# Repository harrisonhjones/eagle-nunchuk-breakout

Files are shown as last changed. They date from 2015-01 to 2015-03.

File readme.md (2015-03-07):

# Nunchuk Breakout
A breakout board for the Wii Nunchuk

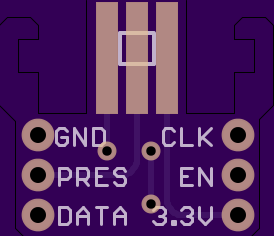
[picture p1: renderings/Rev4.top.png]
PNG


## Version History

| Revision # | Schematic | Board | BOM | Top | Bottom |  Purchase Link | Notes |
| ---- | ---- | ---- | ---- | ---- | ---- | ---- | ---- |
| 0 | N/A | N/A | N/A | N/A | N/A | N/A | Initial Version. No locking mechanism. Produced on a PCB mill @ college. Works |
| 1 | N/A | N/A | N/A | N/A | N/A | N/A | New version with locking mechanism and built to straddle a solderless breakout board |
| 2 | N/A | N/A | N/A | N/A | N/A | N/A | Similar to Rev 1. Now contains alignment square to help show which way the Nunchuck should be plugged in |
| 3 | N/A | N/A | N/A | N/A | N/A | N/A | Added `enable` pin for enabling/disabling the nunchuck so multiple can be used |
| 4 | [SCH](source/Rev4.sch), [PDF](schematics/Rev4.sch.pdf) | [BRD](source/Rev4.brd), [PDF](boards/Rev4.brd.pdf) | N/A | [PNG](renderings/Rev4.top.png) | [PNG](renderings/Rev4.bot.png) | [OSHPark ($2.00 for 3)](https://oshpark.com/projects/nHR9gFSK) | Added hopefully stronger locking section. |
| 5 | [SCH](source/Rev5.sch), [PDF](schematics/Rev5.sch.pdf) | [BRD](source/Rev5.brd), [PDF](boards/Rev5.brd.pdf) | N/A | N/A | N/A | N/A | Added frame on schematic. Moved date to better location. Added open-hardware logo |
| 6 | [SCH](source/Rev6.sch), [PDF](schematics/Rev6.sch.pdf) | [BRD](source/Rev6.brd), [PDF](boards/Rev6.brd.pdf) | N/A | [PNG](renderings/Rev6.top.png) | [PNG](renderings/Rev6.bot.png) | [OSHPark ($2.55 for 3)](https://oshpark.com/projects/g8WnvhAW) | Extended the nunchuk male connector so it clears when on a breadboard |

## To Do

* Rename all versions of `Nunchuck` with 'proper' spelling `nunchuk`

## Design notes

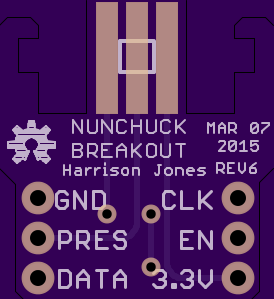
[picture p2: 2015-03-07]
renderings/Rev6.top.png

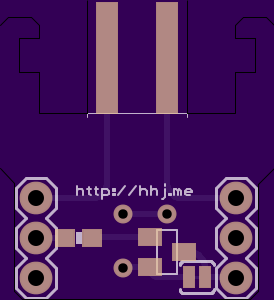
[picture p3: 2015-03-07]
renderings/Rev6.bot.png

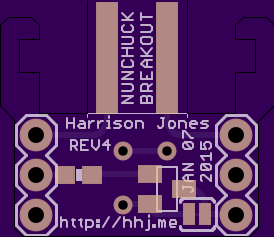
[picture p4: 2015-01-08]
renderings/Rev4.bot.png

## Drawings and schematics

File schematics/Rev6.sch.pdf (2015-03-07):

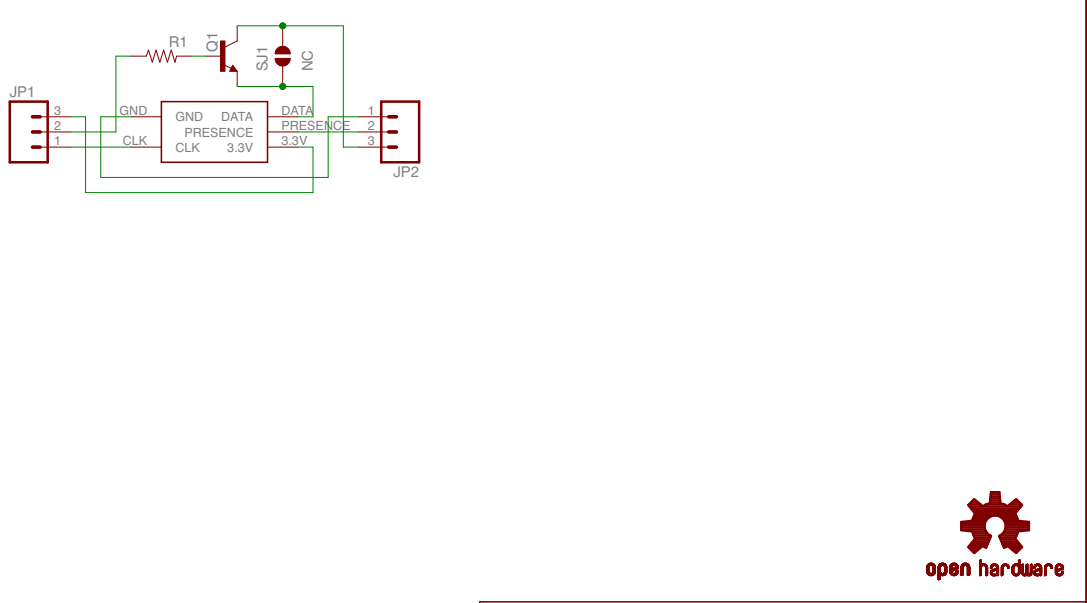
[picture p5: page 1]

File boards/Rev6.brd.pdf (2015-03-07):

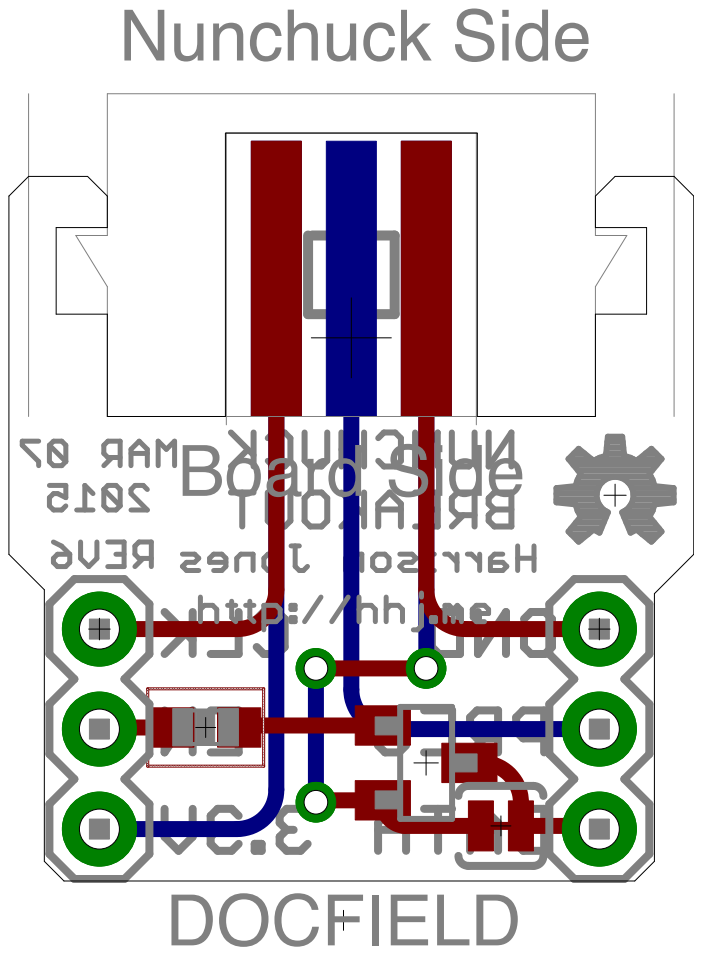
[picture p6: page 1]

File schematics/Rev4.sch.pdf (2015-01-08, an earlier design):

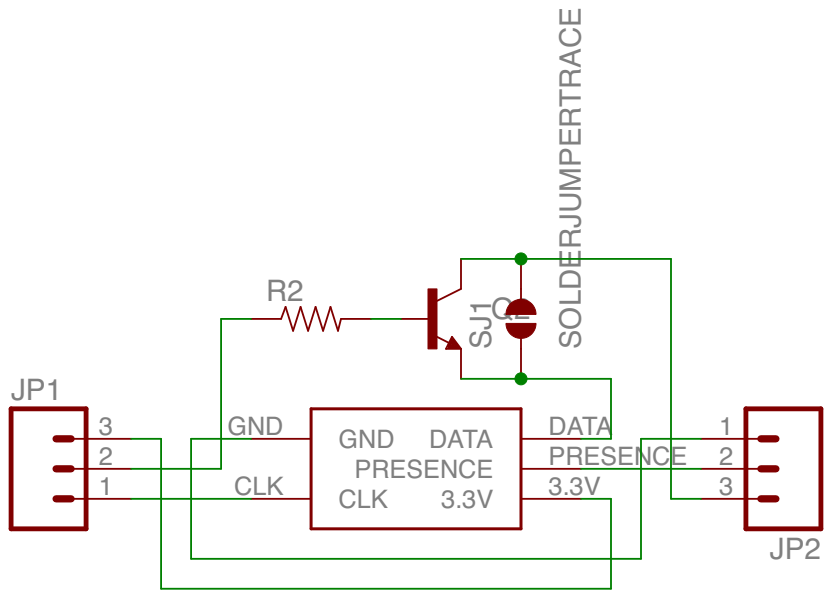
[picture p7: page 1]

SOLDERJUMPERTRACE CLK CLK GND GND 3.3V 3.3V PRESENCE PRESENCE DATA DATA JP1 123 JP2 123 SJ1Q2 R2


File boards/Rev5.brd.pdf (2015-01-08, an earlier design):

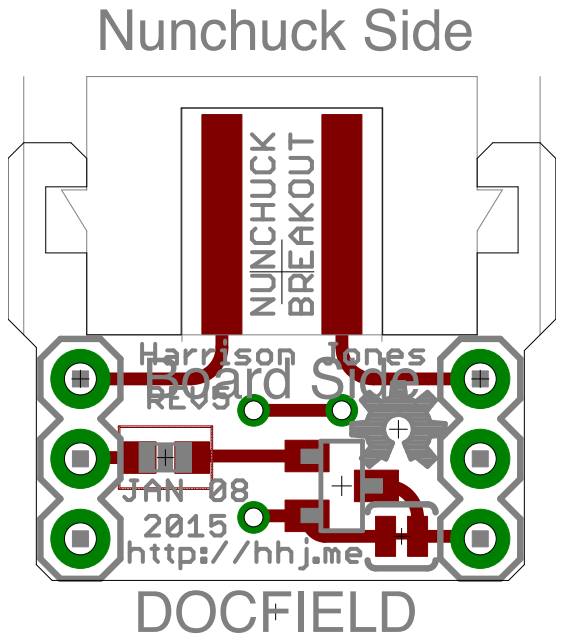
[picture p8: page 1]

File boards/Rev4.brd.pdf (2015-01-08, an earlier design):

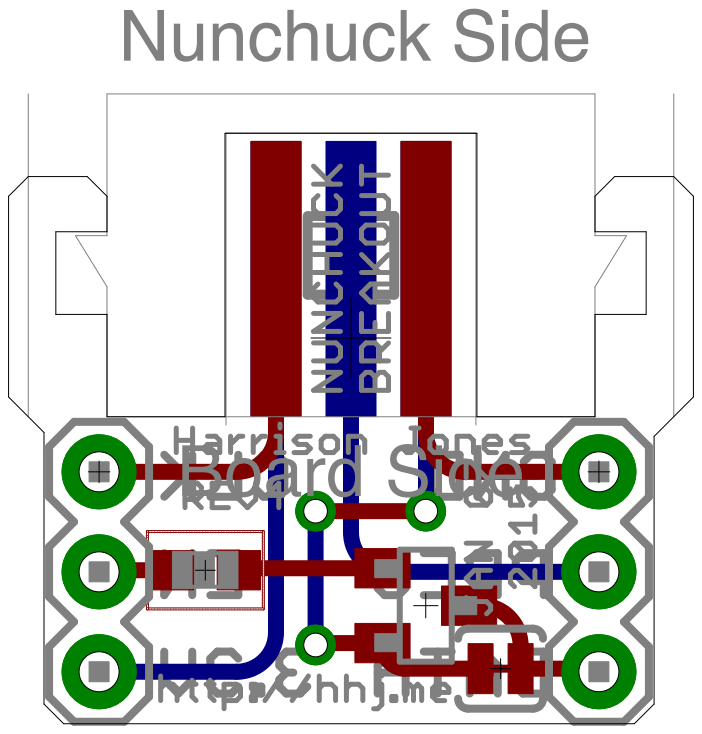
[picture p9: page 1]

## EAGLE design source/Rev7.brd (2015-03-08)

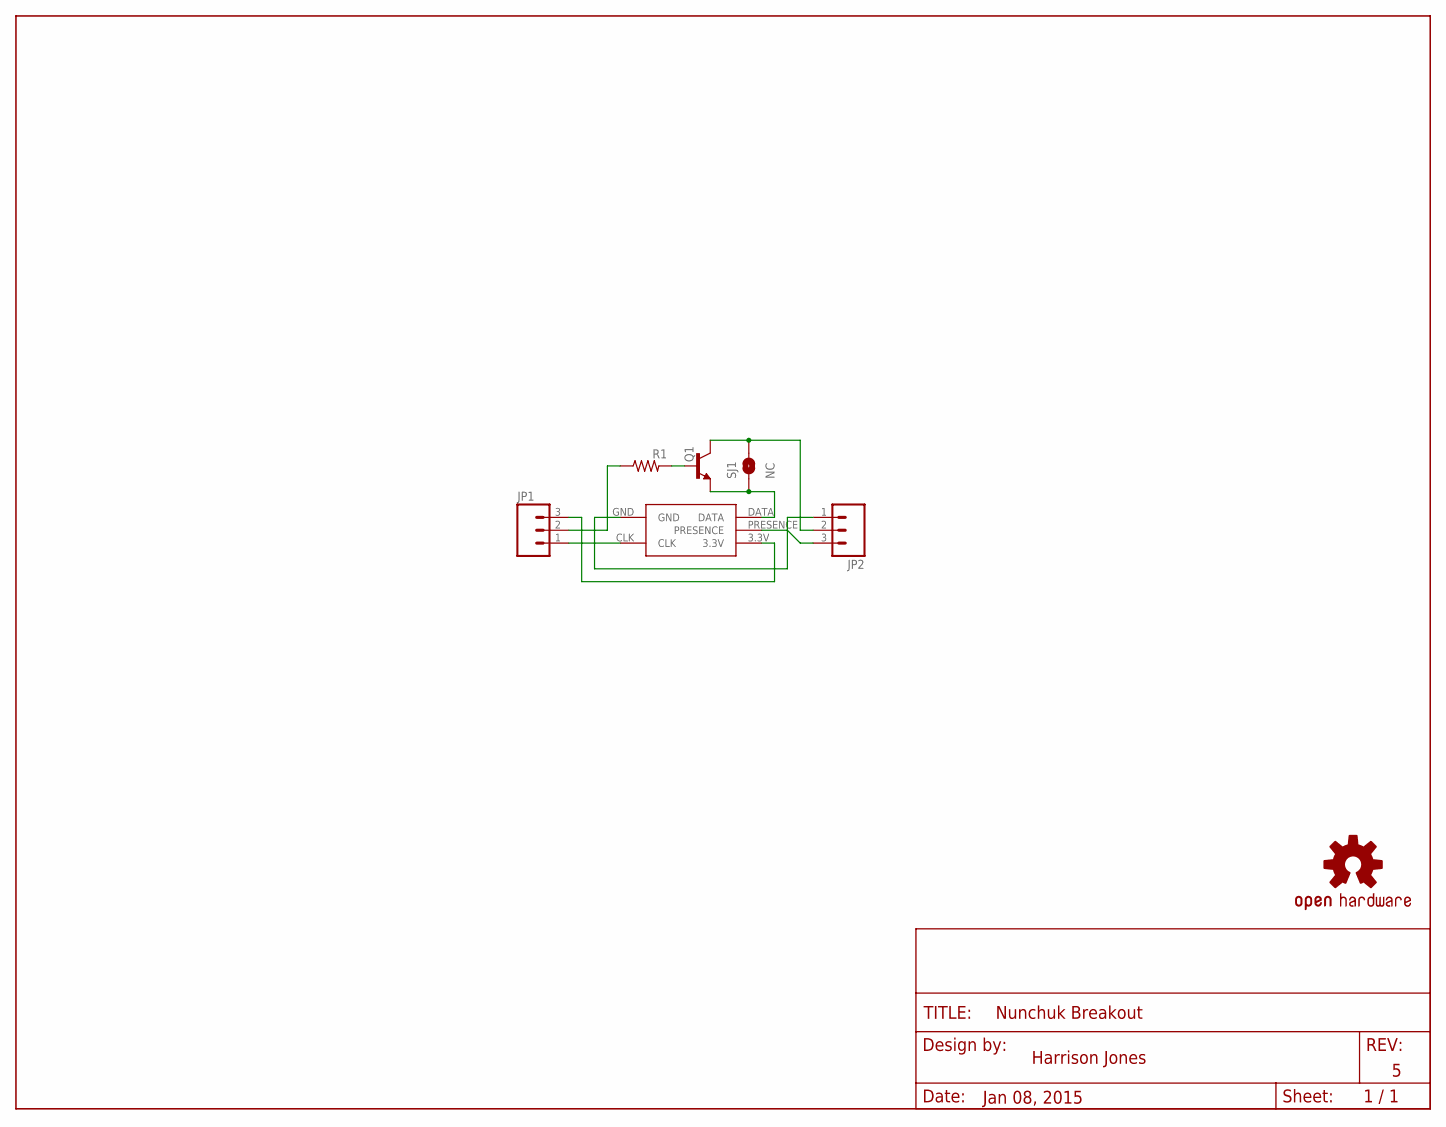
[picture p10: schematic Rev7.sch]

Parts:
JP1, JP2: M03PTH; 1X03
LOGO1: OSHW-LOGOS; OSHW-LOGO-S
Q1: TRANSISTOR_NPNSOT23; SOT23
R1: RESISTOR0603; 0603-RES
SJ1: NC; SJ_2S-TRACE
U$1: NUNCHUCKLOCL; NUNCHUCK-LOCK
U$2: DOC_FIELD

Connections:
3.3V: JP1.3, U$1.3.3V
EN: JP1.2, R1.1
GND: JP2.1, U$1.GND
unnamed: Q1.1 (B), R1.2
unnamed: JP2.3, U$1.PRESENCE
unnamed: JP2.2, Q1.3 (C), SJ1.2
SCL: JP1.1, U$1.CLK
SDA: Q1.2 (E), SJ1.1, U$1.DATA

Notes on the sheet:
Nunchuk Breakout
Harrison Jones
Jan 08, 2015
1 / 1

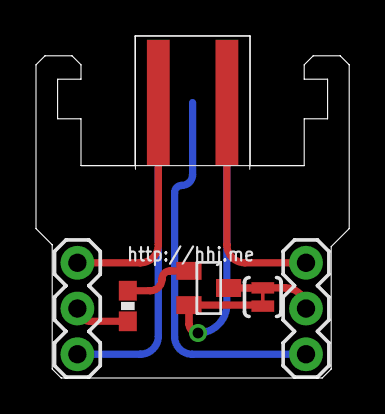
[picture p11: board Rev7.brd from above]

Board: 2 copper layers, 17.4 x 19.0 mm, 8 parts (1 on the bottom side), 8 nets.

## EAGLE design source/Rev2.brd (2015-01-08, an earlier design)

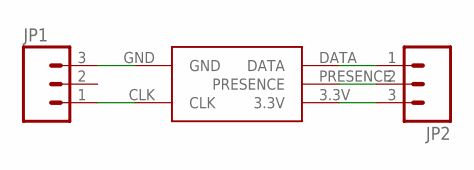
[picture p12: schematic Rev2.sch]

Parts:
JP1, JP2: M03PTH; 1X03
U$1: NUNCHUCKLOCL; NUNCHUCK-LOCK

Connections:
3.3V: JP2.3, U$1.3.3V
CLK: JP1.1, U$1.CLK
DATA: JP2.1, U$1.DATA
GND: JP1.3, U$1.GND
PRESENCE: JP2.2, U$1.PRESENCE

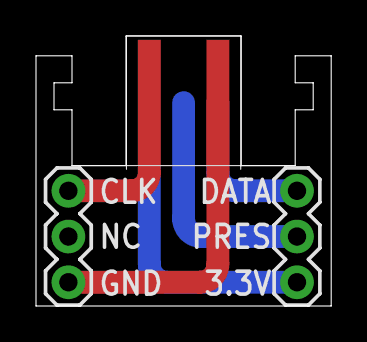
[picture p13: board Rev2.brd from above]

Board: 2 copper layers, 16.4 x 15.0 mm, 3 parts (0 on the bottom side), 5 nets.

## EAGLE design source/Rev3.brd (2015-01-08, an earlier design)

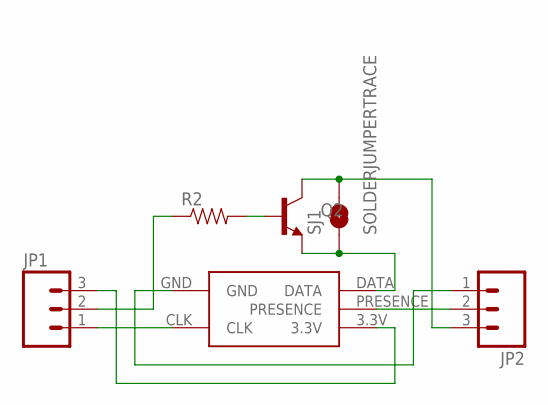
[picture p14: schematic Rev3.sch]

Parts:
JP1, JP2: M03PTH; 1X03
Q2: TRANSISTOR_NPNSOT23; SOT23
R2: RESISTOR0603; 0603-RES
SJ1: SOLDERJUMPERTRACE; SJ_2S-TRACE
U$1: NUNCHUCKLOCL; NUNCHUCK-LOCK

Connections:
3.3V: JP1.3, U$1.3.3V
EN: JP1.2, R2.1
GND: JP2.1, U$1.GND
unnamed: Q2.1 (B), R2.2
unnamed: JP2.3, Q2.3 (C), SJ1.2
PRES: JP2.2, U$1.PRESENCE
SCL: JP1.1, U$1.CLK
SDA: Q2.2 (E), SJ1.1, U$1.DATA

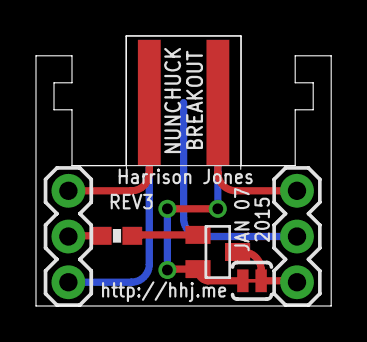
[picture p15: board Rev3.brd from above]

Board: 2 copper layers, 16.4 x 15.0 mm, 6 parts (0 on the bottom side), 8 nets.

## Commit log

2015-01-08 Changed filetree structure
    [Rev0.brd, Rev0.sch, Rev1.brd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]
2015-01-08 Eagle wants source files in same folder
    [Rev0.brd, Rev0.sch, Rev1.brd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]
2015-01-08 Ignoring gerbers
2015-01-08 See readme.md for updates
    [Rev5.brd, Rev5.sch]
2015-03-07 added Rev 6. Board change for better breadboard compatibility
    [Rev6.brd, Rev6.sch]
2015-03-08 Working on Rev 7. Changed layer colors and moved vias around for better text placement
    [Rev7.brd, Rev7.sch]
2015-03-08 Updated Rev7: down to 1 via and much better signal layout. Pin layout has changed
    [Rev7.brd, Rev7.sch]

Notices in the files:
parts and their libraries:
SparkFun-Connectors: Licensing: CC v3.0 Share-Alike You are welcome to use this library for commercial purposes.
